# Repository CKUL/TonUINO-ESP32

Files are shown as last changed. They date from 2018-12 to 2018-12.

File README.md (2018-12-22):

# [TonUINO-ESP32](http://discourse.voss.earth/t/esp32-port-inkl-webinterface/399)
_[TonUINO V2.0](https://www.voss.earth/tonuino/) Code für ESP32 mit Erweiterungen, es gibt zu dem Projekt ebenfalls eine [Discourse Seite](http://discourse.voss.earth/)_

**Aktuell Umgesetzt:**
  
  - Webinterface zur Fernsteuerung
    - Play, Pause, Start, Stop, Lautstärke
    - Equalizer einstellen
    - max. Lautstärke einstellen
    - Ausschalttimer
    - Einschalttimer
    
  - Ambientlight mit WS2812 LED´s
    - ändern der Farbe über Webinterface
    
  - Timer zum Ein- und Ausschalten
    - Sonnenauf- und Untergang simulation für Einschalttimer
    - MP3-Wiedergabe beim Ein- / Ausschalten
    
  - AP-Modus um WLAN konfigurieren zu können ohne dies (SSID, PW) im Code fest zu verankern
    - Sprachansage bei Fehler mit der Verbindung
   
  - Begrüßung beim Einschalten 
   
  - Kopfhörererkennung
    - reduziert die Lautstärke wenn Kopfhörer gesteckt
    - begrenz die Lautstärke wenn Kopfhörer gesteckt
    - schaltet auf vorherige Lautstärke zurück wenn Kopfhörer nicht mehr gesteckt
    
  - Sprachmenü und Struktur auf Tag erweitert um Ambilight Farbe zu speichern
    
  - Funktion der Hoch- Runter- Tasten geändert
    - kurzes Drücken = Lautstärke +/-
    - langes Drücken = Lied +/-
    
 **Noch offen und geplant:**
 
  - Speichern der Einstellungen im EEPROM / Flash
  - Tags verwalten

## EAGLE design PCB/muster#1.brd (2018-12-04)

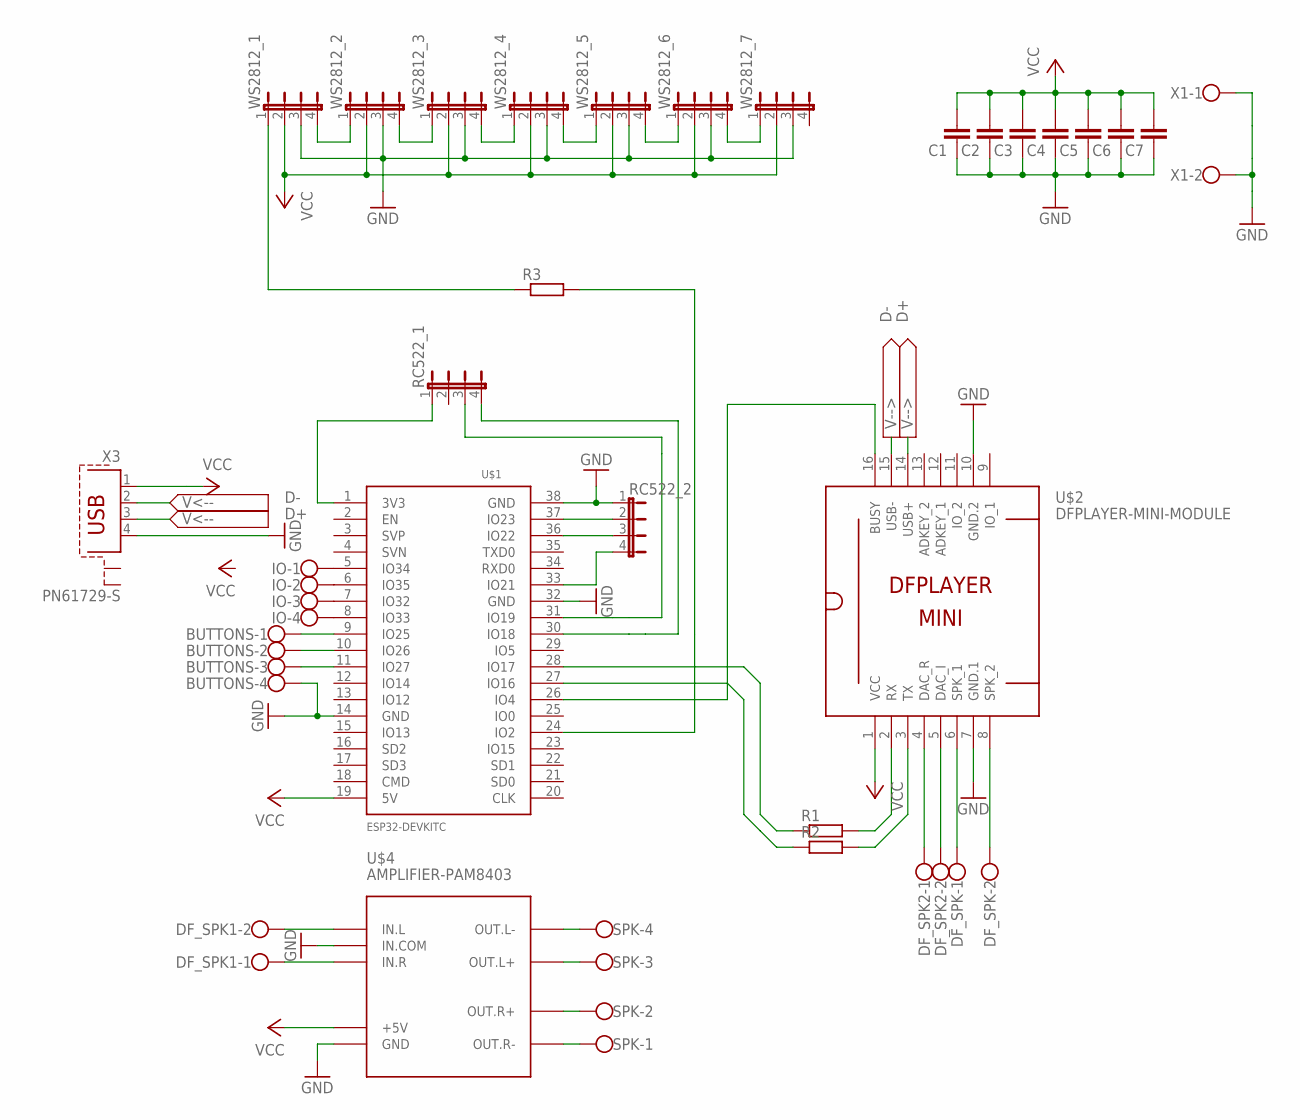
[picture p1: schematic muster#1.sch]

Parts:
BUTTONS: W237-4
C1: C-EU025-024X044; C025-024X044
C2, C3, C4, C5, C6, C7: C-EU025-025X050; C025-025X050
DF_SPK, DF_SPK1, DF_SPK2: W237-02P; W237-132
IO: W237-4
R1, R2, R3: R-EU_0204/2V; 0204V
RC522_1, RC522_2: JP4E; JP4
SPK: W237-4
U$1: ESP32DEVKITC; ESP32-DEVKITC
U$2: DFPLAYER-MINI-MODULE
U$4: AMPLIFIER-PAM8403
WS2812_1, WS2812_2, WS2812_3, WS2812_4, WS2812_5, WS2812_6, WS2812_7: JP4E; JP4
X1: W237-102
X3: PN61729-S

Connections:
D+: U$2.14 (USB+), X3.3
D-: U$2.15 (USB-), X3.2
GND: BUTTONS.4, C1.1, C2.1, C3.1, C4.1, C5.1, C6.1, C7.1, RC522_2.1, U$1.14 (GND), U$1.32 (GND), U$1.38 (GND), U$2.7 (GND.1), U$2.10 (GND.2), U$4.GND, U$4.IN.COM, WS2812_1.3, WS2812_2.3, WS2812_3.3, WS2812_4.3, WS2812_5.3, WS2812_6.3, WS2812_7.3, X1.1, X1.2, X3.4
unnamed: DF_SPK.2, U$2.8 (SPK_2)
unnamed: DF_SPK.1, U$2.6 (SPK_1)
unnamed: BUTTONS.1, U$1.9 (IO25)
unnamed: BUTTONS.2, U$1.10 (IO26)
unnamed: BUTTONS.3, U$1.11 (IO27)
unnamed: R1.1, U$1.28 (IO17)
unnamed: R2.1, U$1.27 (IO16)
unnamed: R2.2, U$2.3 (TX)
unnamed: WS2812_1.4, WS2812_2.1
unnamed: WS2812_2.4, WS2812_3.1
unnamed: R1.2, U$2.2 (RX)
unnamed: SPK.1, U$4.OUT.R-
unnamed: DF_SPK2.1, U$2.4 (DAC_R)
unnamed: R3.1, WS2812_1.1
unnamed: SPK.2, U$4.OUT.R+
unnamed: SPK.3, U$4.OUT.L+
unnamed: SPK.4, U$4.OUT.L-
unnamed: WS2812_3.4, WS2812_4.1
unnamed: WS2812_4.4, WS2812_5.1
unnamed: WS2812_5.4, WS2812_6.1
unnamed: WS2812_6.4, WS2812_7.1
unnamed: DF_SPK2.2, U$2.5 (DAC_I)
unnamed: DF_SPK1.2, U$4.IN.L
unnamed: DF_SPK1.1, U$4.IN.R
unnamed: R3.2, U$1.24 (IO2)
unnamed: RC522_2.2, U$1.37 (IO23)
unnamed: U$1.26 (IO4), U$2.16 (BUSY)
unnamed: RC522_2.3, U$1.36 (IO22)
unnamed: RC522_2.4, U$1.33 (IO21)
unnamed: RC522_1.3, U$1.31 (IO19)
unnamed: RC522_1.4, U$1.30 (IO18)
unnamed: RC522_1.1, U$1.1 (3V3)
unnamed: IO.1, U$1.5 (IO34)
unnamed: IO.2, U$1.6 (IO35)
unnamed: IO.3, U$1.7 (IO32)
unnamed: IO.4, U$1.8 (IO33)
VCC: C1.2, C2.2, C3.2, C4.2, C5.2, C6.2, C7.2, U$1.19 (5V), U$2.1 (VCC), U$4.+5V, WS2812_1.2, WS2812_2.2, WS2812_3.2, WS2812_4.2, WS2812_5.2, WS2812_6.2, WS2812_7.2, X3.1

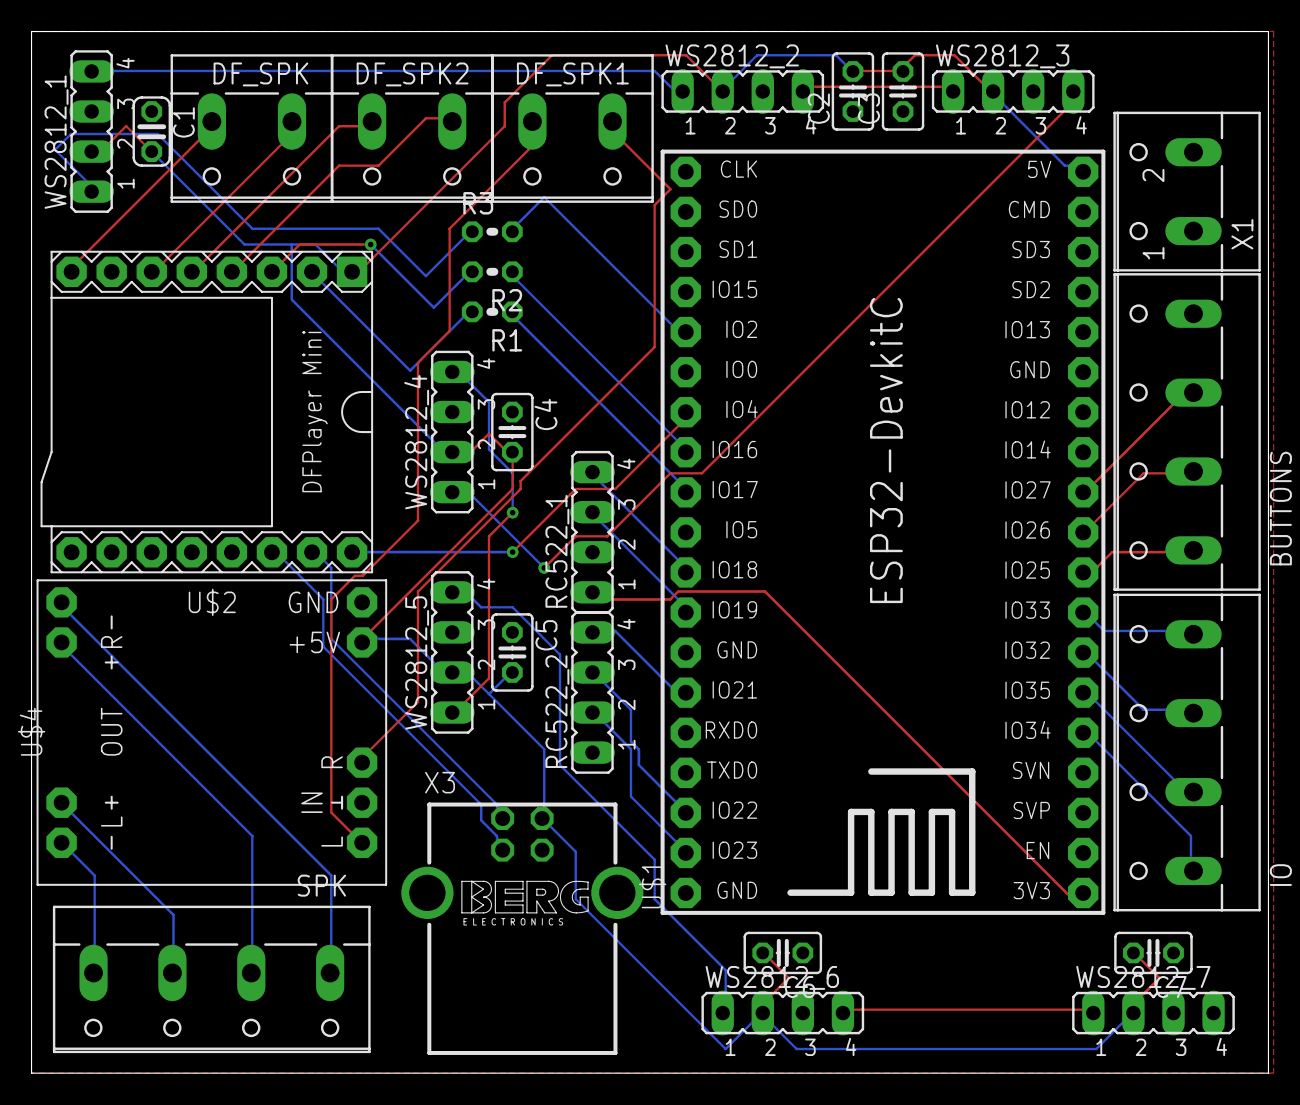
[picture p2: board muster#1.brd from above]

Board: 2 copper layers, 78.4 x 66.0 mm, 30 parts (0 on the bottom side), 40 nets.

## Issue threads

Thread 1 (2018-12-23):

Neuer Code vom 23.12.18 Fehler writeCard

FFKite, 2018-12-23:
Hallo,

super code vielen dank.
ich habe heute versucht die aktuelle version Hochzuladen, er zeigt ein Fehler variable or field `writeCard`declared void. bei der alten version hatte ich keine Probleme.

viele grüße

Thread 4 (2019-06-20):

The EEPROM-methods can not work this way on an ESP32

dl9sec, 2019-06-20:
It seems, that the EEPROM-methods are used the same way as on an AVR based Arduino.
This will not work in this way. I came upon that problem when using an AVR based sketch on an ESP32. The EEPROM class exists for compatibility purpose (exactly this usecase), but need a little extra effort to work propperly.
The compiler will not throw a warning or so, all seems to be all right, but it will not.

An EEPROM size must be defined:
```
#define EEPROM_SIZE 128           // Emulate 128 bytes of EEPROM
```

As far as i see this can be not more than one sector of an ESP32 FLASH which means 4kB.

The EEPROM must be initialized:
```
if (!EEPROM.begin(EEPROM_SIZE))
  {
    Serial.println(F("Failed to initialise EEPROM!"));
  }
```

The EEPROM content must be "commited" to be persistent after using EEPROM.write() (whenever it is useful and not to exceed the maximum FLASH write cycles):

```
EEPROM.commit();
```

As far as i see, RAM memory is allocated as an EEPROM emulation. At initialization the FLASH area is read into that emulation memory. EEPROM manipulation is done within that RAM emulation memory. So if you don't commit, the EEPROM content isn't stored persistent.

Be aware, that EEPROM.length() will not work propperly with the standard initialization!

So i suppose, that the EEPROM content is lost after a suppy interruption with the current sketch...

Regards, Thorsten

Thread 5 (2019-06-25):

Schaltung zur Kopfhörererkennung?

dl9sec, 2019-06-25:
Gibt es irgendwelche Hinweise zur Schaltung der Kopfhörererkennung?
Ich kann im Schaltplan nicht davon finden, auch nicht in den Forks...

Vielen Dank.

Gruß, Thorsten

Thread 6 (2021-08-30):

Schaltplan

ChR-iSz, 2021-08-30:
Verstehe ich das richtig, das der Code für einen ESP32 ist.

Ich habe ein M5 Stack core (geniales Teil !) und würde dort ein Projekt draus machen, um Tonuino auf dem M5 Core laufen zu lassen.

Leider finde ich für die ESP's keinen Schaltplan im Netz. Hast du einen zur Hand ?

VG

Closed 2022-04-11.

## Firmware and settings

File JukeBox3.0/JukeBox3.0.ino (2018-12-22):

// Verwendete Bibliotheken
#include <WiFi.h>
#include <WebServer.h>
#include <NTPClient.h>
#include <WiFiUdp.h>
#include <TonUINO_html.h>
#include <Arduino.h>
#include "DFRobotDFPlayerMini.h"
#include <SPI.h>
#include <MFRC522.h>
#include <EEPROM.h>
#include <JC_Button.h>
#include <math.h>
#include <FastLED.h>
#include <Preferences.h>

//EEPROM Speicher *NVS*
Preferences preferences;
int timeout = 20;


//========================================================================
//Hier nur VAriablen zum Testen

int l = 0;
bool headphoneIn =0 ;
int success = 0;
int success2 = 0;

bool debug = false; // Auf true setzen um debug Informationen über die Serielle Schnittstelle zu erhalten.

//Variablen zum Speichern von EInstellungen
//========================================================================

unsigned long last_color = 0xFFFFFF;
unsigned int last_Volume;
unsigned int last_max_Volume;


//========================================================================
//WS2812b Einstellungen

#define DATA_PIN 2 //signal pin 
#define NUM_LEDS 7 //number of LEDs in your strip
#define BRIGHTNESS 32  //brightness  (max 254) 
#define LED_TYPE WS2811  // I know we are using ws2812, but it's ok!
#define COLOR_ORDER GRB
CRGB leds[NUM_LEDS];

//============Sunrise Variablen===========================================
DEFINE_GRADIENT_PALETTE( sunrise_gp ) {
  0,     0,  0,  0,   //schwarz
128,   240,  0,  0,   //rot
224,   240,240,  0,   //gelb
255,   128,128,240 }; //sehr helles Blau

static uint16_t heatIndex = 0; // start out at 0

//========================================================================
//NTP Variablen
WebServer server(80);
WiFiUDP ntpUDP;
NTPClient timeClient(ntpUDP);

//Variable zum Auslesen der HTML Antwort
String TimerOFF = "00:00";
String TimerON = "00:00";
uint8_t TMR_OFF_HH, TMR_OFF_MM,TMR_ON_HH,TMR_ON_MM;
int TMR_OFF_REP = 0;
int TMR_ON_REP = 0;
unsigned int max_Volume = 20;
unsigned int akt_Volume = 10;
bool TMP_OFFTIME = true;
bool TMP_ONTIME = true;
bool WakeUpLight = false;
bool SleepLight = false;
bool startSR = false;

//Set Pins for RC522 Module
const int resetPin = 22; // Reset pin
const int ssPin = 21;    // Slave select pin

//Objekt zur kommunikation mit dem Modul anlegen
MFRC522 mfrc522 = MFRC522(ssPin, resetPin); // Create instance

// this object stores nfc tag data
struct nfcTagObject {
  uint32_t cookie;
  uint8_t version;
  uint8_t folder;
  uint8_t mode;
  uint8_t special;
  uint32_t color;
};

//=======================Funktionen Deklarieren==============================

nfcTagObject myCard;
void resetCard(void);
bool readCard(nfcTagObject *nfcTag);
void setupCard(void);
static void nextTrack();
void startTimer(void);
void stoppTimer(void);
int voiceMenu(int numberOfOptions, int startMessage, int messageOffset,
              bool preview = false, int previewFromFolder = 0);

bool knownCard = false;
uint16_t numTracksInFolder;
uint16_t track;

//====================Timer Deklaration=====================================

hw_timer_t * timer = NULL;
volatile SemaphoreHandle_t timerSemaphore;
portMUX_TYPE timerMux = portMUX_INITIALIZER_UNLOCKED;

volatile uint32_t isrCounter = 0;
volatile uint32_t lastIsrAt = 0;

void IRAM_ATTR onTimer(){
  // Increment the counter and set the time of ISR
  portENTER_CRITICAL_ISR(&timerMux);
  isrCounter++;
  lastIsrAt = millis();
  portEXIT_CRITICAL_ISR(&timerMux);
  // Give a semaphore that we can check in the loop
  xSemaphoreGiveFromISR(timerSemaphore, NULL);
  // It is safe to use digitalRead/Write here if you want to toggle an output
}

// implement a notification class,
// its member methods will get called
//
class Mp3Notify {
public:
  static void OnError(uint16_t errorCode) {
    // see DfMp3_Error for code meaning
    Serial.println();
    Serial.print("Com Error ");
    Serial.println(errorCode);
  }
  static void OnPlayFinished(uint16_t track) {
    Serial.print("Track beendet");
    Serial.println(track);
    delay(100);
    nextTrack();
  }
  static void OnCardOnline(uint16_t code) {
    Serial.println(F("SD Karte online "));
  }
  static void OnCardInserted(uint16_t code) {
    Serial.println(F("SD Karte bereit "));
  }
  static void OnCardRemoved(uint16_t code) {
    Serial.println(F("SD Karte entfernt "));
  }
};

HardwareSerial mySoftwareSerial(2);
DFRobotDFPlayerMini myDFPlayer;
void printDetail(uint8_t type, int value);

// Leider kann das Modul keine Queue abspielen.
static void nextTrack() {
  if (knownCard == false)
    // Wenn eine neue Karte angelernt wird soll das Ende eines Tracks nicht
    // verarbeitet werden
    return;

  if (myCard.mode == 1) {
    Serial.println(F("Hörspielmodus ist aktiv -> Strom sparen"));
    myDFPlayer.sleep();
  }
  if (myCard.mode == 2) {
    if (track != numTracksInFolder) {
      track = track + 1;
      myDFPlayer.playFolder(myCard.folder, track);
      Serial.print(F("Albummodus ist aktiv -> nächster Track: "));
      Serial.print(track);
    } else
      myDFPlayer.sleep();
  }
  if (myCard.mode == 3) {
    track = random(1, numTracksInFolder + 1);
    Serial.print(F("Party Modus ist aktiv -> zufälligen Track spielen: "));
    Serial.println(track);
    myDFPlayer.playFolder(myCard.folder, track);
  }
  if (myCard.mode == 4) {
    Serial.println(F("Einzel Modus aktiv -> Strom sparen"));
    myDFPlayer.sleep();
  }
  if (myCard.mode == 5) {
    if (track != numTracksInFolder) {
      track = track + 1;
      Serial.print(F("Hörbuch Modus ist aktiv -> nächster Track und "
                     "Fortschritt speichern"));
      Serial.println(track);
      myDFPlayer.playFolder(myCard.folder, track);
      // Fortschritt im EEPROM abspeichern
      EEPROM.write(myCard.folder, track);
    } else
      myDFPlayer.sleep();
      // Fortschritt zurück setzen
      EEPROM.write(myCard.folder, 1);
  }
  delay(500);
}

static void previousTrack() {
  if (myCard.mode == 1) {
    Serial.println(F("Hörspielmodus ist aktiv -> Track von vorne spielen"));
    myDFPlayer.playFolder(myCard.folder, track);
  }
  if (myCard.mode == 2) {
    Serial.println(F("Albummodus ist aktiv -> vorheriger Track"));
    if (track != 1) {
      track = track - 1;
    }
    myDFPlayer.playFolder(myCard.folder, track);
  }
  if (myCard.mode == 3) {
    Serial.println(F("Party Modus ist aktiv -> Track von vorne spielen"));
    myDFPlayer.playFolder(myCard.folder, track);
  }
  if (myCard.mode == 4) {
    Serial.println(F("Einzel Modus aktiv -> Track von vorne spielen"));
    myDFPlayer.playFolder(myCard.folder, track);
  }
  if (myCard.mode == 5) {
    Serial.println(F("Hörbuch Modus ist aktiv -> vorheriger Track und "
                     "Fortschritt speichern"));
    if (track != 1) {
      track = track - 1;
    }
    myDFPlayer.playFolder(myCard.folder, track);
    // Fortschritt im EEPROM abspeichern
    EEPROM.write(myCard.folder, track);
  }
}


MFRC522::MIFARE_Key key;
bool successRead;
byte sector = 1;
byte blockAddr = 4;
byte trailerBlock = 7;
MFRC522::StatusCode status;

#define buttonPause 25
#define buttonUp 26
#define buttonDown 27
#define busyPin 4
#define headphonePin 32
#define dfpMute 33

#define LONG_PRESS 1000

Button pauseButton(buttonPause);
Button upButton(buttonUp,100);
Button downButton(buttonDown,100);
bool ignorePauseButton = false;
bool ignoreUpButton = false;
bool ignoreDownButton = false;

uint8_t numberOfCards = 0;

bool isPlaying() { return !digitalRead(busyPin); }


//Funktion um die Antworten der HTML Seite auszuwerten
void handleRestart(){
  // Restart ESP
  ESP.restart();
}
void handleSetup(){
  server.send ( 200, "text/html", SetupPage());
  if (server.args() > 0 ) { // Arguments were received
    for ( uint8_t i = 0; i < server.args(); i++ ) {
      
      Serial.print("Vom Server wurde folgendes empfangen: "); // Display the argument
      Serial.print(server.argName(i)); // Display the argument
      Serial.print("=");
      Serial.println(server.arg(i));
      
      if(server.argName(i) == "ssid" ){
        Serial.print("Speichere SSID: ");
        Serial.println(server.arg(i));
        preferences.putString("SSID", server.arg(i));
   
      }
        
      else if(server.argName(i) == "pw"){
        Serial.print("Speichere PW: ");
        Serial.println(server.arg(i));
        preferences.putString("Password", server.arg(i));

      }


      
       
    }
     
  }

}
void handleRoot(){ 
     server.send ( 200, "text/html", getPage() );
  if (server.args() > 0 ) { // Arguments were received
    for ( uint8_t i = 0; i < server.args(); i++ ) {

      Serial.print("Vom Server wurde folgendes empfangen: "); // Display the argument
      Serial.print(server.argName(i)); // Display the argument
      Serial.print("=");
      Serial.println(server.arg(i));
     
      if(server.argName(i) == "appt-time-off" ){

          TimerOFF = server.arg(i);
          char charBuf[TimerOFF.length() + 1];
          TimerOFF.toCharArray(charBuf, TimerOFF.length()+1);
          TMR_OFF_HH = atof(strtok(charBuf, ":"));
          TMR_OFF_MM = atof(strtok(NULL, ":"));
          Serial.print("Die eingelesene Zeit für TimerOFF: ");
          Serial.print(TMR_OFF_HH);
          Serial.print(":");
          Serial.println(TMR_OFF_MM);
          TMR_OFF_REP = 0;
          TMP_OFFTIME = false;
          
      }
        
      else if(server.argName(i) == "cb_tmr_off"){
        TMR_OFF_REP = 1;
        Serial.println("Für den TimerOFF wurde eine Wiederholung eingestellt");
        }

      else if(server.argName(i) == "appt-time-on"){
        
          TimerON = server.arg(i);
          char charBuf[TimerON.length() + 1];
          TimerON.toCharArray(charBuf, TimerON.length()+1);
          TMR_ON_HH = atof(strtok(charBuf, ":"));
          TMR_ON_MM = atof(strtok(NULL, ":"));
          Serial.print("Die eingelesene Zeit für TimerON: ");
          Serial.print(TMR_ON_HH);
          Serial.print(":");
          Serial.println(TMR_ON_MM);
          TMR_ON_REP = 0;
          TMP_ONTIME = false;
        }

      else if(server.argName(i) == "cb_tmr_on"){
        TMR_ON_REP = 1;
        Serial.println("Für den TimerON wurde eine Wiederholung eingestellt");
        }

      else if(server.argName(i) == "akt_volume"){
        myDFPlayer.volume(server.arg(i).toInt());
        akt_Volume = myDFPlayer.readVolume();
        Serial.println("Die aktuelle Lütstärke wurde geändert");
        }
      else if(server.argName(i) == "max_volume"){
        max_Volume = server.arg(i).toInt();
        Serial.println("Die maximale Lütstärke wurde geändert");
        }
      else if(server.argName(i) == "LED_color"){
        Serial.println("Die Farbe der LEDs wird geändert: " + server.arg(i));
         String Color = server.arg(i);
         char *ptr;
         char charBuf[Color.length() + 1];
         Color.toCharArray(charBuf, Color.length()+1);
         unsigned long col = strtol(charBuf,&ptr,16);
        fill_solid(leds, NUM_LEDS, col); // Farbe aller LEDs ändern
        FastLED.show(); 
      }
      else if(server.argName(i) == "LED_bri"){
        Serial.println("Die Helligkeit der LEDs wird geändert ");
        Serial.println("Helligkeit = " + server.arg(i));
        FastLED.setBrightness(server.arg(i).toInt());
        FastLED.show(); 
      }
      else if(server.argName(i) == "cb_SleepLight_on"){
          //CODE HERE
          if(server.arg(i).toInt()==1){
              SleepLight = true;
          }
      }
      else if(server.argName(i) == "cb_SleepLight_off"){
          if(server.arg(i).toInt()==0){
              SleepLight = false;
          }
      }
      else if(server.argName(i) == "cb_WakeUpLight_on"){
          if(server.arg(i).toInt()==1){
              WakeUpLight = true;
          }
          
      }
      else if(server.argName(i) == "cb_WakeUpLight_off"){
          if(server.arg(i).toInt()==0){
              WakeUpLight = false;
          }
      }

      
       
      }
     
    }
}
    


//===================================================================================
//Ab hier Aktionen welche bei drücken eines Button auf der HTML Seite ausgelöst werden
void handlePrev() { 
 Serial.println("handlePrev");
 myDFPlayer.previous();
 server.send(200, "text/html", getPage());
}
 
void handlePlay() { 
 Serial.println("handlePlay");
 myDFPlayer.start();
 server.send(200, "text/html", getPage()); 
}

void handlePause() { 
 Serial.println("handlePause");
 myDFPlayer.pause();
 server.send(200, "text/html", getPage()); 
}

void handleNext() { 
 Serial.println("handleNext");
 myDFPlayer.next();
 server.send(200, "text/html", getPage()); 
}

void handleVol_up() { 
 Serial.println("handleVol+");
 myDFPlayer.volumeUp();
 akt_Volume = myDFPlayer.readVolume();
 server.send(200, "text/html", getPage()); 
}
 
void handleVol_down() { 
 Serial.println("handleVol-");
 myDFPlayer.volumeDown();
 akt_Volume = myDFPlayer.readVolume();
 server.send(200, "text/html", getPage()); 
}


void handleEQ_NORM() { 
 Serial.println("handleEQ_Norm");
 myDFPlayer.EQ(DFPLAYER_EQ_NORMAL);
 server.send(200, "text/html", getPage()); 
}
 
void handleEQ_POP() { 
 Serial.println("handleEQ_POP");
 myDFPlayer.EQ(DFPLAYER_EQ_POP);
 server.send(200, "text/html", getPage()); 
}
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
void loop(){
 
  do {
    
    if (xSemaphoreTake(timerSemaphore, 0) == pdTRUE){//Timer Interrupt Routine
      uint32_t isrCount = 0, isrTime = 0;
      // Read the interrupt count and time
      portENTER_CRITICAL(&timerMux);
      isrCount = isrCounter;
      isrTime = lastIsrAt;
      portEXIT_CRITICAL(&timerMux);
      //Ab hier Funktionen für Timer

      if(success == 1) TimeCompare(); //Abfrage der Zeit im Sekundentakt
      if(startSR == true) sunrise();
      

    }
    server.handleClient();
    
    
if (!isPlaying()) {
  if (myDFPlayer.available()) {
      printDetail(myDFPlayer.readType(), myDFPlayer.read()); //Print the detail message from DFPlayer to handle different errors and states.
  }
}
    // Buttons werden nun über JS_Button gehandelt, dadurch kann jede Taste
    // doppelt belegt werden
    pauseButton.read();
    upButton.read();
    downButton.read();
    
    //Erkennung ob ein Kopfhörer eingesteckt ist, "headphoneIn" verriegelt jeweils die Abfrage so das sie nur einmal durchlaufen wird
    if ((digitalRead(headphonePin)== 1) && (headphoneIn == 0)){

      Serial.println("Kopfhörer wurde eingesteckt");
      digitalWrite(dfpMute, HIGH);
      headphoneIn = 1;
      last_max_Volume = max_Volume; // Das letzte max. Volume merken
      last_Volume = myDFPlayer.readVolume();
      max_Volume = 10;
      if(myDFPlayer.readVolume() >= max_Volume){
          myDFPlayer.volume(10);
      }
      
    } else if ((digitalRead(headphonePin)== 0) && (headphoneIn == 1)){
      Serial.println("Kopfhörer wurde entfernt");
      headphoneIn = 0;
      max_Volume = last_max_Volume;
      myDFPlayer.volume(last_Volume);
      }

 if (pauseButton.wasReleased()) {
      if (ignorePauseButton == false){
        if (isPlaying()){
          myDFPlayer.pause();
          fill_solid(leds, NUM_LEDS, CRGB::Black); // Farbe aller LEDs ändern
          FastLED.show();
          startSR = false;
           heatIndex=0;
        }else{
          myDFPlayer.start();
          ignorePauseButton = false;
    }
   }
 }else if (pauseButton.pressedFor(LONG_PRESS) &&
               ignorePauseButton == false){
      Serial.println(F("Pause taste wurde lang gedrückt"));
      if (isPlaying()){
        myDFPlayer.advertise(track);}
      else {
        knownCard = false;
        myDFPlayer.playMp3Folder(800);
        Serial.println(F("Karte resetten..."));
        resetCard();
        mfrc522.PICC_HaltA();
        mfrc522.PCD_StopCrypto1();
      }
      ignorePauseButton = true;
    } 

    if (upButton.pressedFor(LONG_PRESS)) {
      //Serial.println(F("Volume Up"));
      //myDFPlayer.volumeUp();
      nextTrack();
      ignoreUpButton = true;
      delay(1000);
    } else if (upButton.wasReleased()) {
      if (!ignoreUpButton){
        //nextTrack();
        if(myDFPlayer.readVolume() <= max_Volume){
          myDFPlayer.volumeUp();
          }
      }else{
        ignoreUpButton = false;}
    }

    if (downButton.pressedFor(LONG_PRESS)) {
      //Serial.println(F("Volume Down"));
      //myDFPlayer.volumeDown();
      previousTrack();
      ignoreDownButton = true;
      delay(1000);
    } else if (downButton.wasReleased()) {
      if (!ignoreDownButton)
        //previousTrack();
        myDFPlayer.volumeDown();
      else
        ignoreDownButton = false;
    }
    

    
    // Ende der Buttons
  } while (!mfrc522.PICC_IsNewCardPresent());

  // RFID Karte wurde aufgelegt

  if (!mfrc522.PICC_ReadCardSerial())
    return;

  if (readCard(&myCard) == true) {
    if (myCard.cookie == 322417479 && myCard.folder != 0 && myCard.mode != 0) {

      knownCard = true;
      numTracksInFolder = myDFPlayer.readFileCountsInFolder(myCard.folder);

      // Hörspielmodus: eine zufällige Datei aus dem Ordner
      if (myCard.mode == 1) {
        Serial.println(F("Hörspielmodus -> zufälligen Track wiedergeben"));
        track = random(1, numTracksInFolder + 1);
        Serial.println(track);
        myDFPlayer.playFolder(myCard.folder, track);
        fill_solid(leds, NUM_LEDS, myCard.color); // Farbe aller LEDs ändern
        FastLED.show();
      }
      // Album Modus: kompletten Ordner spielen
      if (myCard.mode == 2) {
        Serial.println(F("Album Modus -> kompletten Ordner wiedergeben"));
        track = 1;
        myDFPlayer.playFolder(myCard.folder, track);
        fill_solid(leds, NUM_LEDS, myCard.color); // Farbe aller LEDs ändern
        FastLED.show();
      }
      // Party Modus: Ordner in zufälliger Reihenfolge
      if (myCard.mode == 3) {
        Serial.println(
            F("Party Modus -> Ordner in zufälliger Reihenfolge wiedergeben"));
        track = random(1, numTracksInFolder + 1);
        myDFPlayer.playFolder(myCard.folder, track);
        fill_solid(leds, NUM_LEDS, myCard.color); // Farbe aller LEDs ändern
      }
      // Einzel Modus: eine Datei aus dem Ordner abspielen
      if (myCard.mode == 4) {
        Serial.println(
            F("Einzel Modus -> eine Datei aus dem Odrdner abspielen"));
        track = myCard.special;
        myDFPlayer.playFolder(myCard.folder, track);
        fill_solid(leds, NUM_LEDS, myCard.color); // Farbe aller LEDs ändern
        FastLED.show();
      }
      // Hörbuch Modus: kompletten Ordner spielen und Fortschritt merken
      if (myCard.mode == 5) {
        Serial.println(F("Hörbuch Modus -> kompletten Ordner spielen und "
                         "Fortschritt merken"));
        track = EEPROM.read(myCard.folder);
        if(track==0)track=1;
        myDFPlayer.playFolder(myCard.folder, track);
        fill_solid(leds, NUM_LEDS, myCard.color); // Farbe aller LEDs ändern
        FastLED.show();
      }
    }

    // Neue Karte konfigurieren
    else {
      knownCard = false;
      setupCard();
    }
  }
  mfrc522.PICC_HaltA();
  mfrc522.PCD_StopCrypto1();
  
}


int voiceMenu(int numberOfOptions, int startMessage, int messageOffset,
              bool preview , int previewFromFolder) {
  int returnValue = 0;
  if (startMessage != 0)
    myDFPlayer.playMp3Folder(startMessage);
  do {
    pauseButton.read();
    upButton.read();
    downButton.read();
    //myDFPlayer.loop();
    if (pauseButton.wasPressed()) {
      if (returnValue != 0)
        return returnValue;
      delay(1000);
    }

    if (upButton.pressedFor(LONG_PRESS)) {
      returnValue = fmin(returnValue + 10, numberOfOptions);
      myDFPlayer.playMp3Folder(messageOffset + returnValue);
      delay(1000);
      if (preview) {
        do {
          delay(10);
        } while (isPlaying());
        if (previewFromFolder == 0)
          myDFPlayer.playFolder(returnValue, 1);
        else
          myDFPlayer.playFolder(previewFromFolder, returnValue);
      }
      ignoreUpButton = true;
    } else if (upButton.wasReleased()) {
      if (!ignoreUpButton) {
        returnValue = fmin(returnValue + 1, numberOfOptions);
        myDFPlayer.playMp3Folder(messageOffset + returnValue);
        delay(1000);
        if (preview) {
          do {
            delay(10);
          } while (isPlaying());
          if (previewFromFolder == 0)
            myDFPlayer.playFolder(returnValue, 1);
          else
            myDFPlayer.playFolder(previewFromFolder, returnValue);
        }
      } else
        ignoreUpButton = false;
    }
    
    if (downButton.pressedFor(LONG_PRESS)) {
      returnValue = fmax(returnValue - 10, 1);
      myDFPlayer.playMp3Folder(messageOffset + returnValue);
      delay(1000);
      if (preview) {
        do {
          delay(10);
        } while (isPlaying());
        if (previewFromFolder == 0)
          myDFPlayer.playFolder(returnValue, 1);
        else
          myDFPlayer.playFolder(previewFromFolder, returnValue);
      }
      ignoreDownButton = true;
    } else if (downButton.wasReleased()) {
      if (!ignoreDownButton) {
        returnValue = fmax(returnValue - 1, 1);
        myDFPlayer.playMp3Folder(messageOffset + returnValue);
        delay(1000);
        if (preview) {
          do {
            delay(10);
          } while (isPlaying());
          if (previewFromFolder == 0)
            myDFPlayer.playFolder(returnValue, 1);
          else
            myDFPlayer.playFolder(previewFromFolder, returnValue);
        }
      } else
        ignoreDownButton = false;
    }
  } while (true);
}

void resetCard() {
  do {
    pauseButton.read();
    upButton.read();
    downButton.read();

    if (upButton.wasReleased() || downButton.wasReleased()) {
      Serial.print(F("Abgebrochen!"));
      myDFPlayer.playMp3Folder(802);
      return;
    }
  } while (!mfrc522.PICC_IsNewCardPresent());

  if (!mfrc522.PICC_ReadCardSerial())
    return;

  Serial.print(F("Karte wird neu Konfiguriert!"));
  setupCard();
}
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

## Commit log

2018-12-04 erstes Leiterplattendesign
    [muster#1.brd, muster#1.sch]
2018-12-05 neuen Ordner angelegt
    [muster#1.brd, muster#1.sch]
2018-12-07 Sprachmenü erweitert zum Speichern der Ambilightfarbe auf dem RFID-Tag
2018-12-22 neue Funktionen
    + WiFi-AP zum Einrichten des WLAN
    + Begrüßung beim Starten der Box
    + Jingles für Timer
    + Ansage bei WLAN Fehler
2018-12-22 neue Seite
    Seite zum Einrichten des WLAN und Neu-Starten der Box

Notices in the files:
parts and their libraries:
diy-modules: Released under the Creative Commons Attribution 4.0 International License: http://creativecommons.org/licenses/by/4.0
